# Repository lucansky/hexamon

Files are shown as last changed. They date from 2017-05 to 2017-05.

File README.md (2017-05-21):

# Hexamon.io - modular wireless beehive weighting system

Beehive monitoring - solves data acquisition from load cells placed under the beehives, data transport to server and data visualization for user.

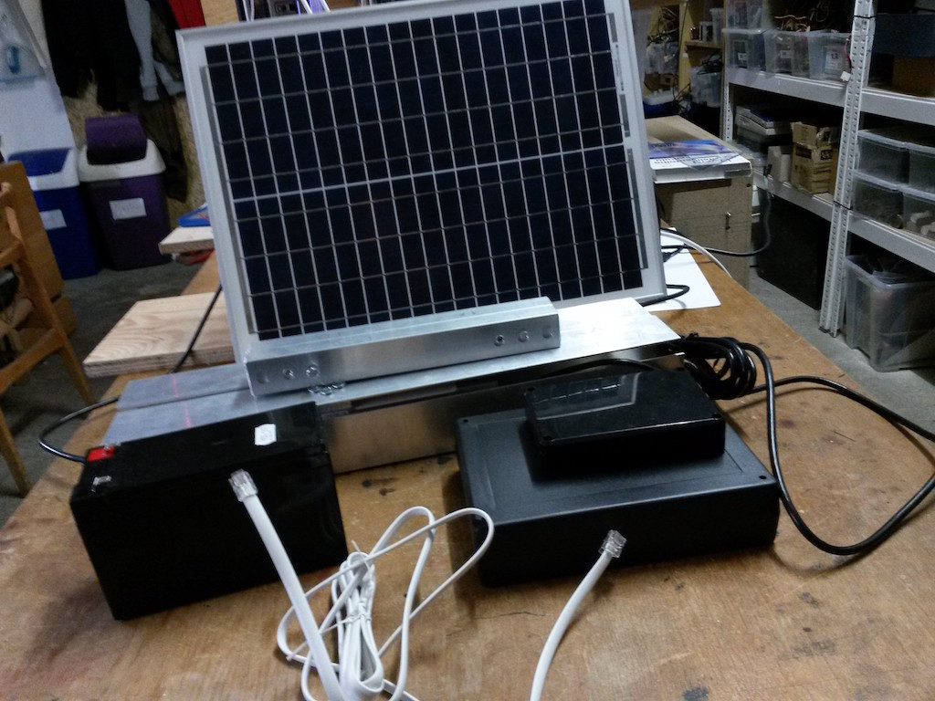
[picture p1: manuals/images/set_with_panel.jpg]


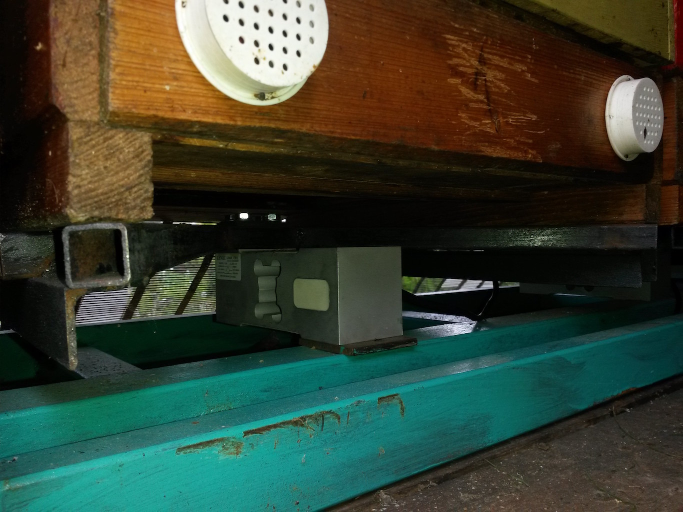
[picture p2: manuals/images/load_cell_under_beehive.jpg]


## Architecture overview
### Master
Master unit consist of a Raspberry Pi with a CAN shield with RJ12 connector.
CAN shield is a board with SPI [MCP2515 CAN controller](http://ww1.microchip.com/downloads/en/DeviceDoc/21801d.pdf) and [SN65HVD23x](http://www.ti.com/lit/ds/symlink/sn65hvd230.pdf) CAN transceiver.

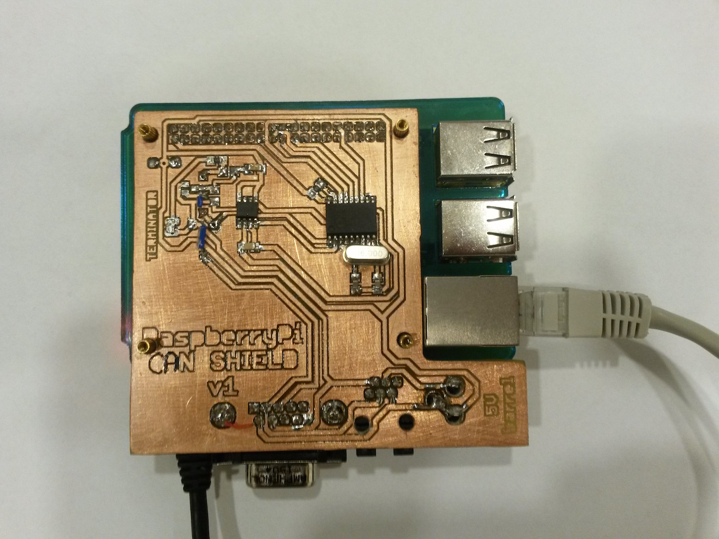
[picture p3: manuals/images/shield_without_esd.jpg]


### Power management
The system is powered through a [18V solar panel](https://www.i4wifi.cz/Solarni-panely-1/Solarni-panely/Solarni-panel-GWL-Sunny-Poly-20-Wp-36-cells-MPPT-18V.html), charging [12V battery](https://www.gme.cz/oloveny-akumulator-shimastu-npg7-2-12-12v-7-2ah).
Enclosure with master unit has power management board for charging circuit with under-voltage protection, as well as 5V USB ports for output.

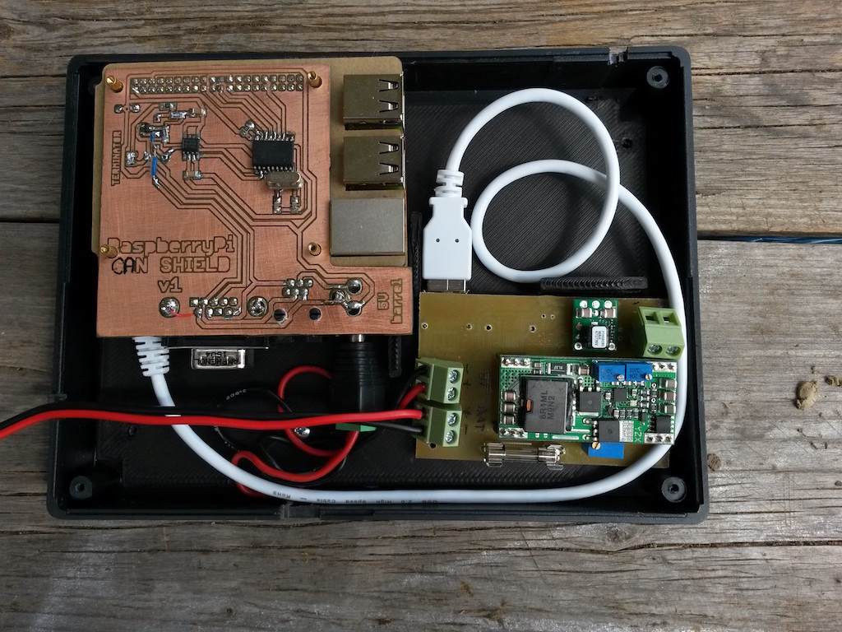
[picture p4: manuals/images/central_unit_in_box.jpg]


20W solar panel was selected for a prototype, due to it's ability to supply sufficient energy even during cloudy days for a Raspberry Pi.

### Bus unit
Under each beehive, assuming that whole chain of beehives is no longer than 100m, is placed platform with load cells for measuring the weight and bus unit in an enclosure. First beehive in chain contains Master and Bus unit at once.

Bus unit has STM32F042F6P6 in an TSSOP20 package with CAN transceiver and two RJ12 connectors for daisy-chaining to other bus units, as well as two holders for HX711 breakout boards. [Converters boards](https://www.aliexpress.com/item/10pcs-HX711-Weighing-Sensor-Dual-Channel-24-Bit-Precision-A-D-Module-Pressure-Sensor/32656264280.html) can be purchased through eBay or AliExpress.

Schematics & board design can be found in _boards_ directory.

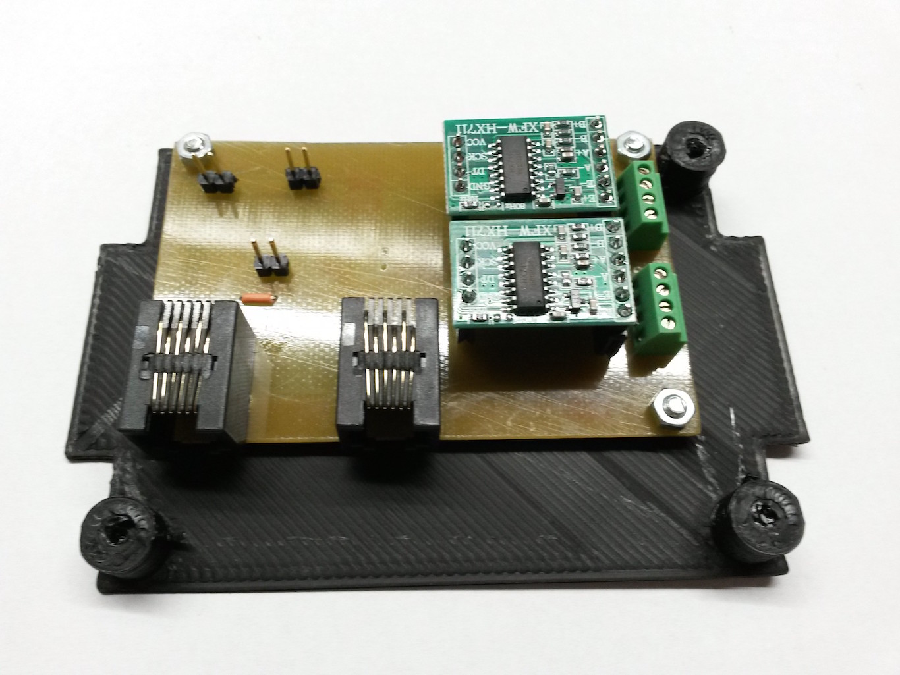
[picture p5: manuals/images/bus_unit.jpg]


### Weight acquisition
As an ADC with differential amplifier was selected chip HX711 integrated on a beakout board with all the necessary electronics around.

## Hardware
### Platform
Simple two-rail platform consists of three components:
* Load cell Zemic L6E or equivalent
* 2x Spacer
* 50x50mm 45cm L profile with drilled holes to match load-cell

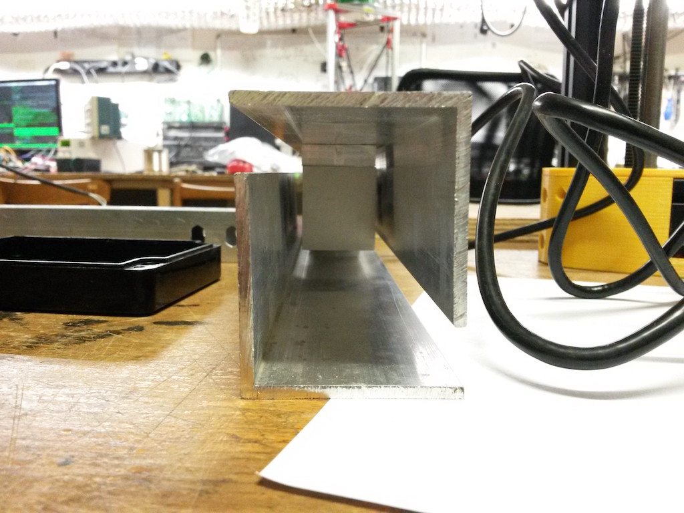
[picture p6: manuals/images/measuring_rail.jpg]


Middle bars may be optional, depending on the situation:
* 2x Rectangle aluminium profile 25x15x3mm 25cm
* 2x Rectangle aluminium profile 25x30x3mm 25cm
These fit perfectly together. By drilling holes, pitch can be adjusted.

As the platform was not part of the project assignment, [contact me](mailto:adamlucansky@gmail.com) in case of interest.

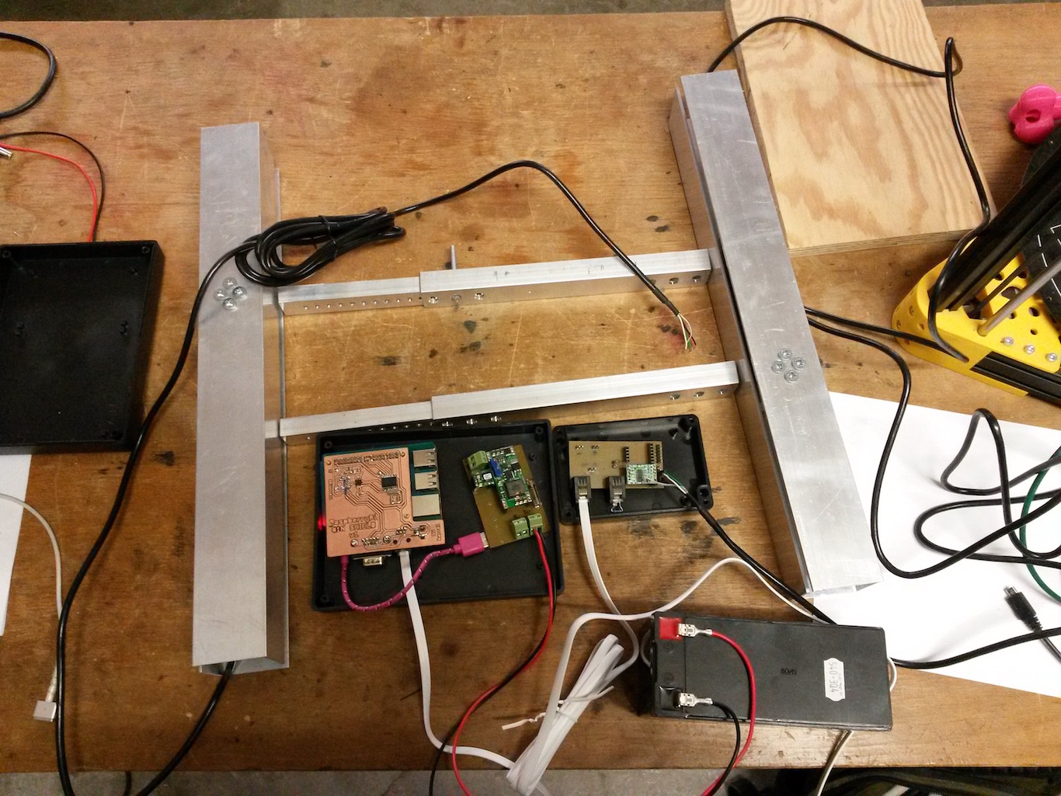
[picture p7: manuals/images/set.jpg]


### Load cells
During development, [Zemic L6E](https://www.zemiceurope.com/media/Documentation/L6E_Datasheet.pdf) were selected. For deployment, [L6G](https://www.zemiceurope.com/media/Documentation/L6G_Datasheet.pdf) are used. 

## Modularity
Several beehives can be chained together with a telephone cable with RJ12 jack through Bus unit under beehive, while master unit is sending captured data wirelessly to server through WiFi (3G/GSM modem option was tested and implemented, but is not further described, wvdial utility & whole ecosystem of linux drivers for modems make it diffucult for set-up).

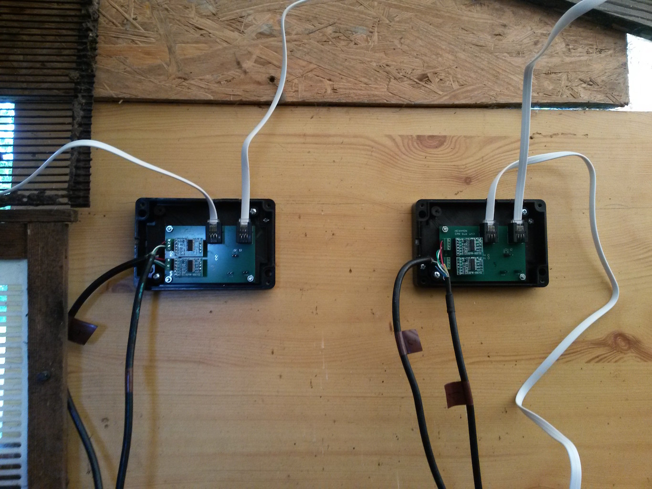
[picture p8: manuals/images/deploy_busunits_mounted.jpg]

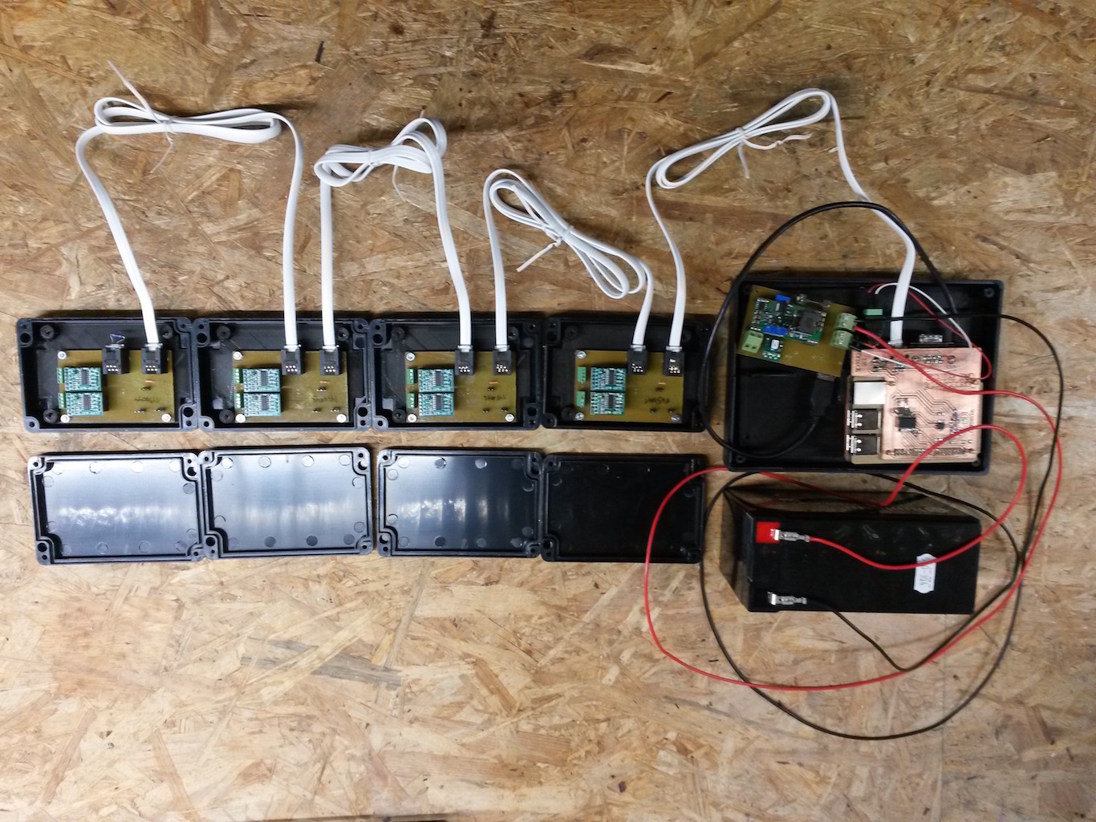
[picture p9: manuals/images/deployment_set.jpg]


## Software
### Master unit
Raspberry Pi 3 running Raspbian system, with an SPI overlay, provides can0 network interface which can be easily interfaced through linux socket. [Main program](https://github.com/lucansky/hexamond) is written in Haskell and is basically flipping frames received on CAN bus to HTTP requests to webservers where the data are further processed.

### Bus unit
[STM32F042](http://www.st.com/en/microcontrollers/stm32f0x2.html) MCU on board has 32kB of Flash memory and 6kB SRAM. Ivory language has been selected for generation of the C code, and Ivory framework as a hardware abstraction layer, message passing and RTOS interaction. Therefore whole project is 100% Haskell except the web. Firmware can be found [HERE](https://github.com/lucansky/hexamon-firmware).

### Web
Web interface provides charts for all sensors connected to the network as well as dashboard defined by user for aggregated statistics. Each setup requires separate instance of the web with database. Source code can be found [HERE](https://github.com/lucansky/hexamon-web)

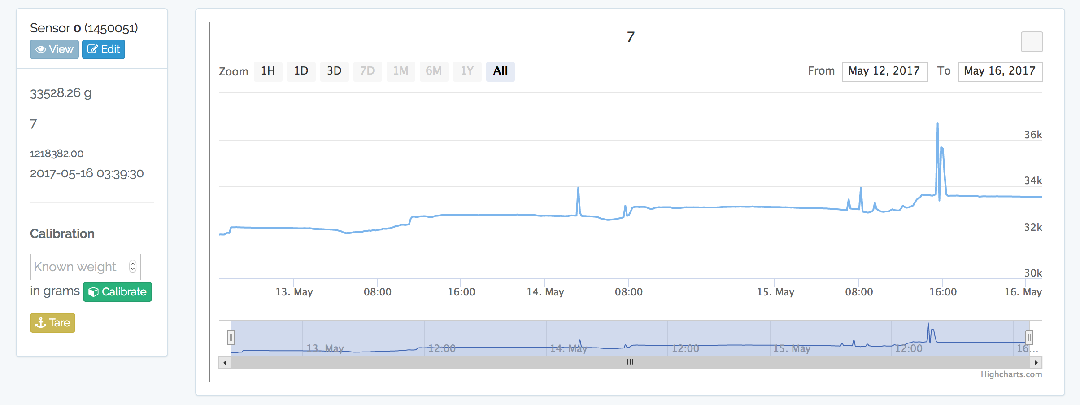
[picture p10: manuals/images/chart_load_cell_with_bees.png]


# Results
System is deployed on a few beehives, needs a bit more tweaking (grounding of the metal platform with beehives, as interference is generated during thunderstorm) and better cable management.

__candump__ can be seed on monitor of the laptop of the deployment set. Battery is already charging from solar panel.
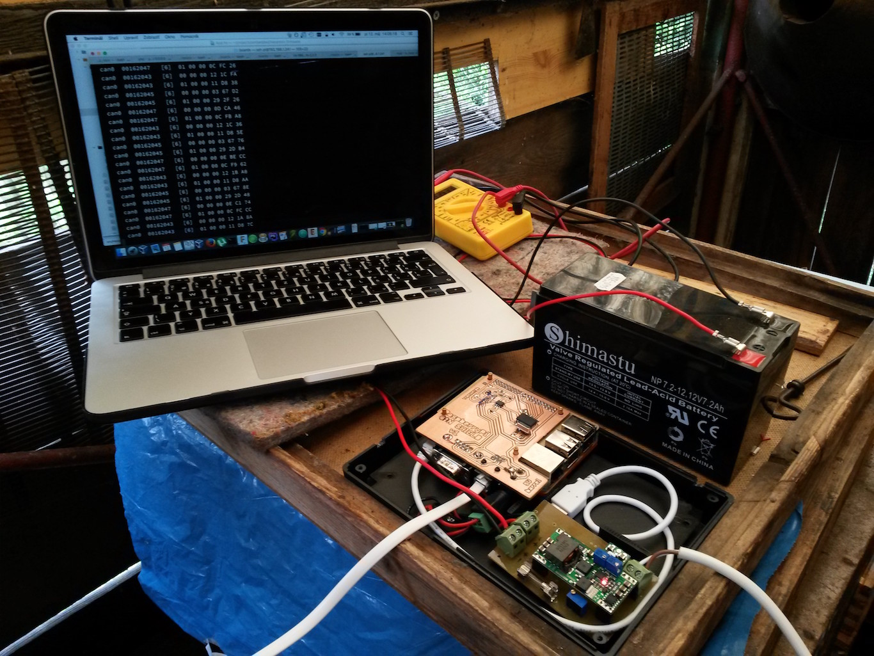
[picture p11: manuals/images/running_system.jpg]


# Future work
Due to over-engineered solution, next iteration will be with [SIGFOX](https://en.wikipedia.org/wiki/Sigfox) - one module per beehive (just load cell cable connected to small box, 2xAA battery, optionally DS18B20 temperature sensor). Currently waiting for a [better signal coverage in Slovakia](http://www.simplecell.sk/pages/technologia_sigfox/), which is the reason SIGFOX was not considered from the beginning.

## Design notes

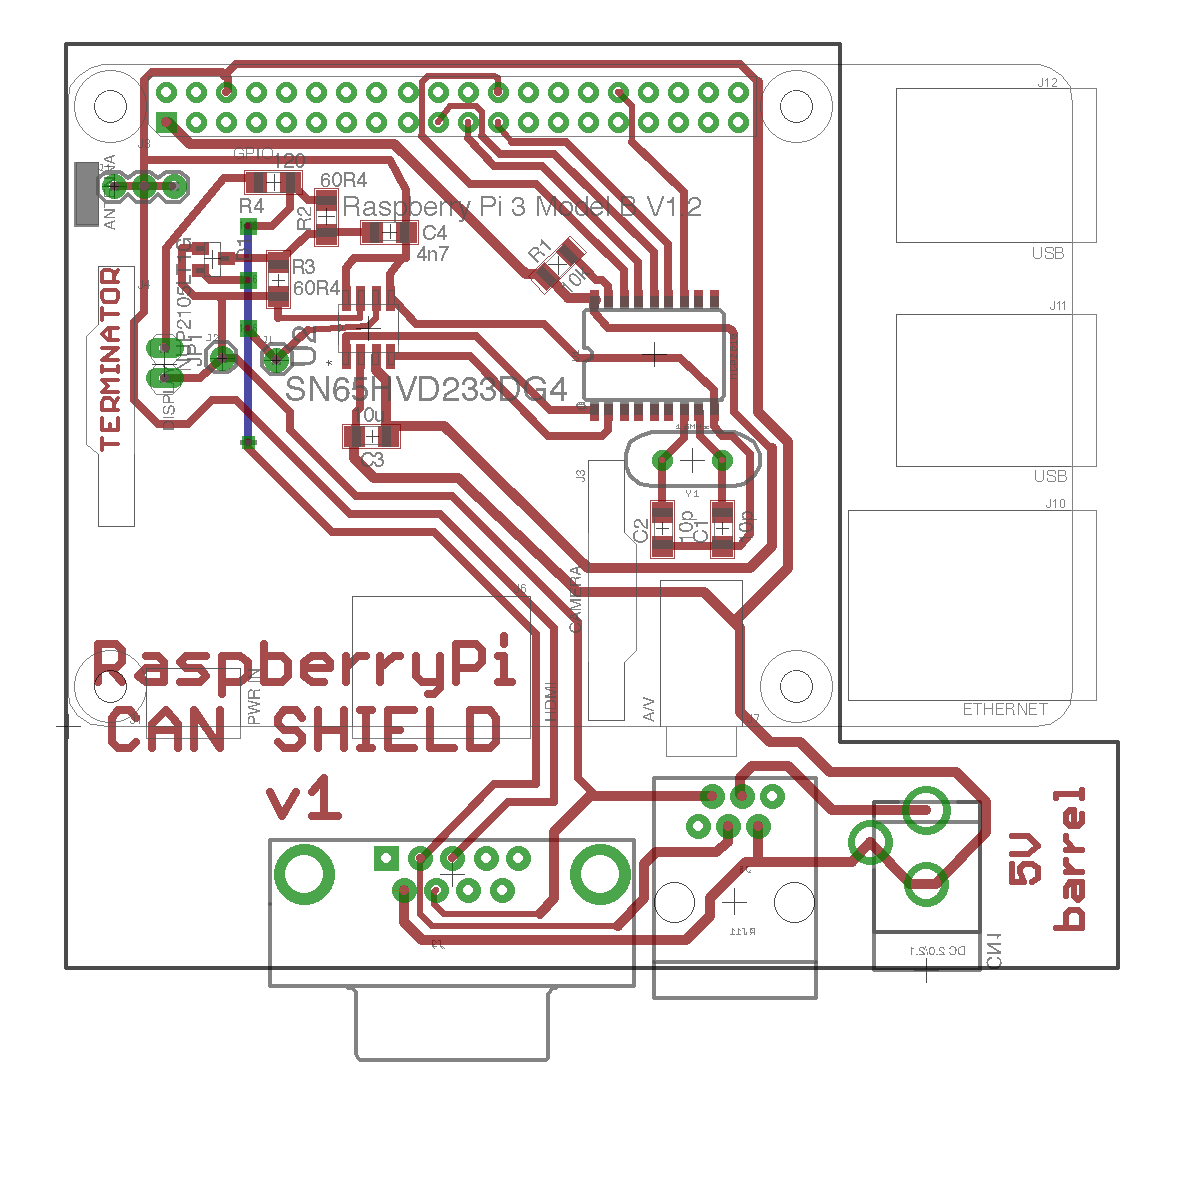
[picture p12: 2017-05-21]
boards/master_can_shield/board_image.png

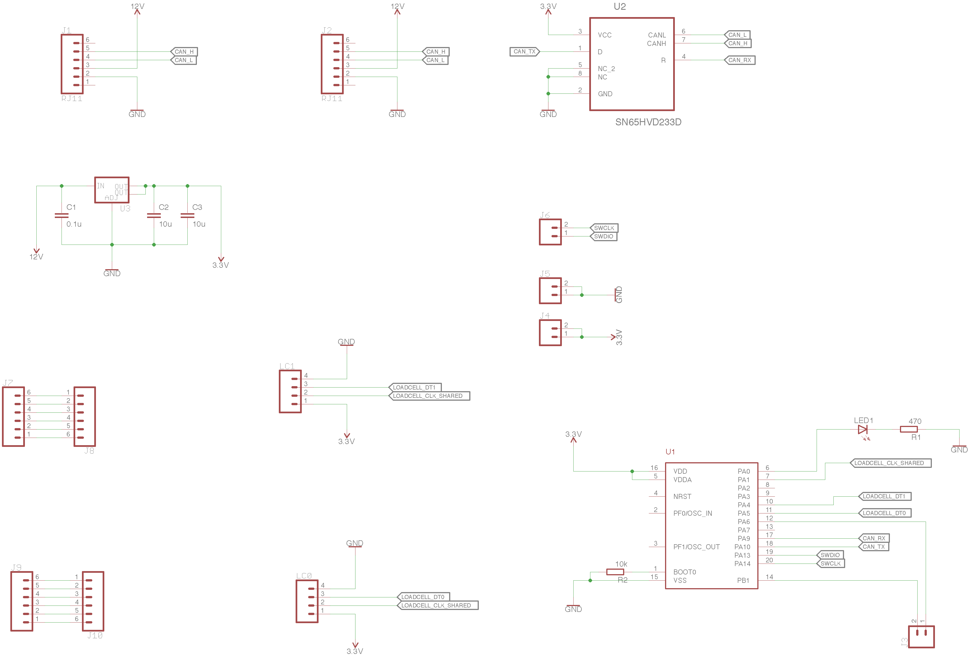
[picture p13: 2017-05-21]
boards/busunit/schema_image.png

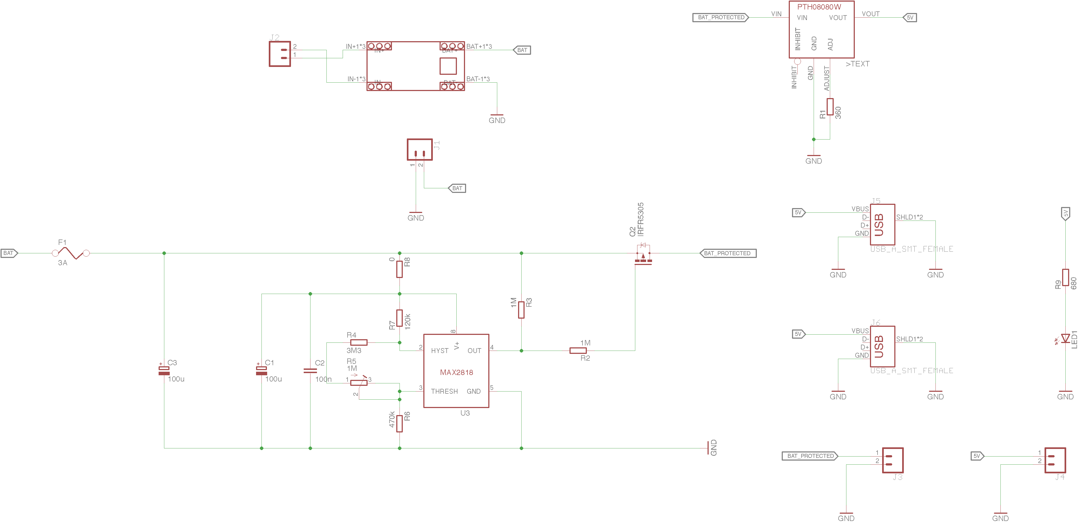
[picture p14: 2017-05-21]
boards/power_board/schema_image.png

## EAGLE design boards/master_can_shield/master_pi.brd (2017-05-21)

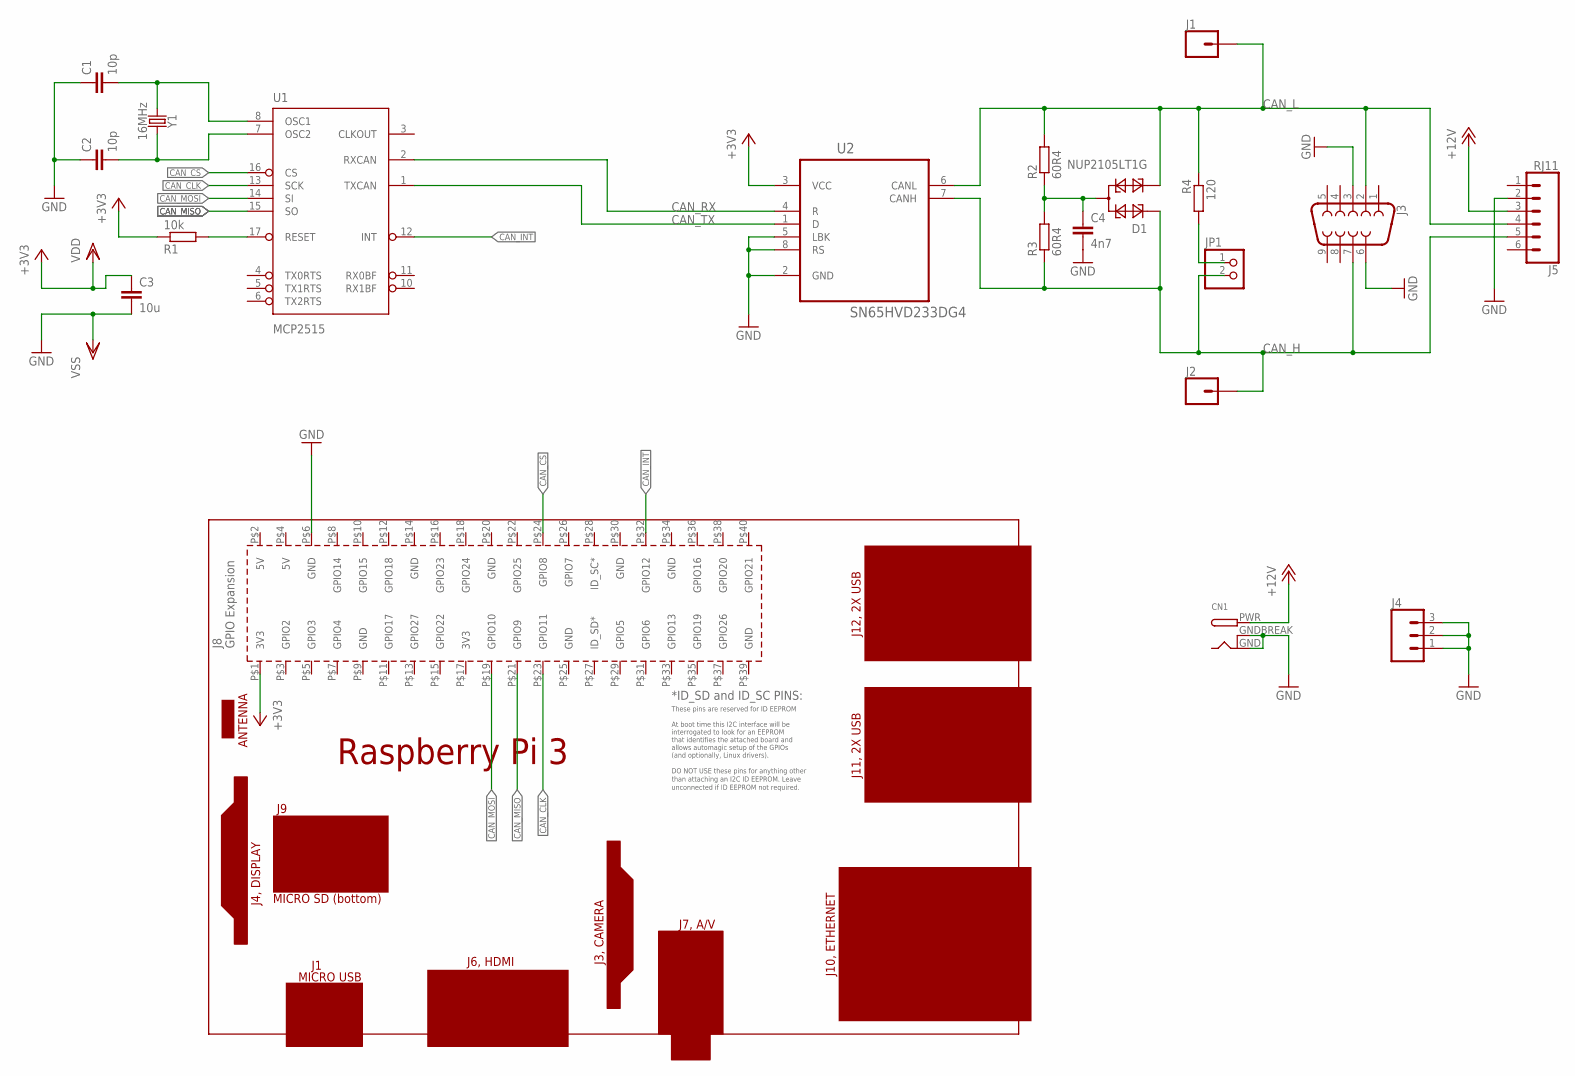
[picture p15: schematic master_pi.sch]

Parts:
C1, C2: 10p; C1206
C3: 10u; C1206
C4: 4n7; C1206
CN1: DCBARRELPTH; DCJACK_2MM_PTH
D1: NUP2105LT1G; SOT23
J1, J2: CONN_01; 1X01
J3: DB9FEMALE; DB9
J4: CONN_03; 1X03
J5: RJ11; RJ11-6
JP1: PINHD-1X2; 1X02
PCB1: RPI3
R1: 10k; R1206
R2, R3: 60R4; R1206
R4: 120; R1206
U1: MCP2515; SO18W
U2: SN65HVD233DG4; SOIC127P600X175-8N
Y1: 16MHz; HC49US

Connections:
+3V3: C3.1, PCB1.P$1 (3V3), R1.1, U1.18 (VDD), U2.3 (VCC)
+12V: CN1.PWR, J5.3
CAN_CLK: PCB1.P$23 (GPIO11), U1.13 (SCK)
CAN_CS: PCB1.P$24 (GPIO8), U1.16 (CS)
CAN_H: D1.1, J2.1, J3.7, J5.5, JP1.2, R3.1, U2.7 (CANH)
CAN_INT: PCB1.P$32 (GPIO12), U1.12 (INT)
CAN_L: D1.2, J1.1, J3.2, J5.4, R2.2, R4.1, U2.6 (CANL)
CAN_MISO: PCB1.P$21 (GPIO9), U1.15 (SO)
CAN_MOSI: PCB1.P$19 (GPIO10), U1.14 (SI)
CAN_RX: U1.2 (RXCAN), U2.4 (R)
CAN_TX: U1.1 (TXCAN), U2.1 (D)
GND: C1.1, C2.1, C3.2, C4.2, CN1.GND, CN1.GNDBREAK, J3.3, J3.6, J4.1, J4.2, J4.3, J5.2, PCB1.P$6 (GND), U1.9 (VSS), U2.2 (GND), U2.5 (LBK), U2.8 (RS)
unnamed: R1.2, U1.17 (RESET)
unnamed: C4.1, D1.3, R2.1, R3.2
unnamed: C1.2, U1.8 (OSC1), Y1.1
unnamed: C2.2, U1.7 (OSC2), Y1.2
unnamed: JP1.1, R4.2

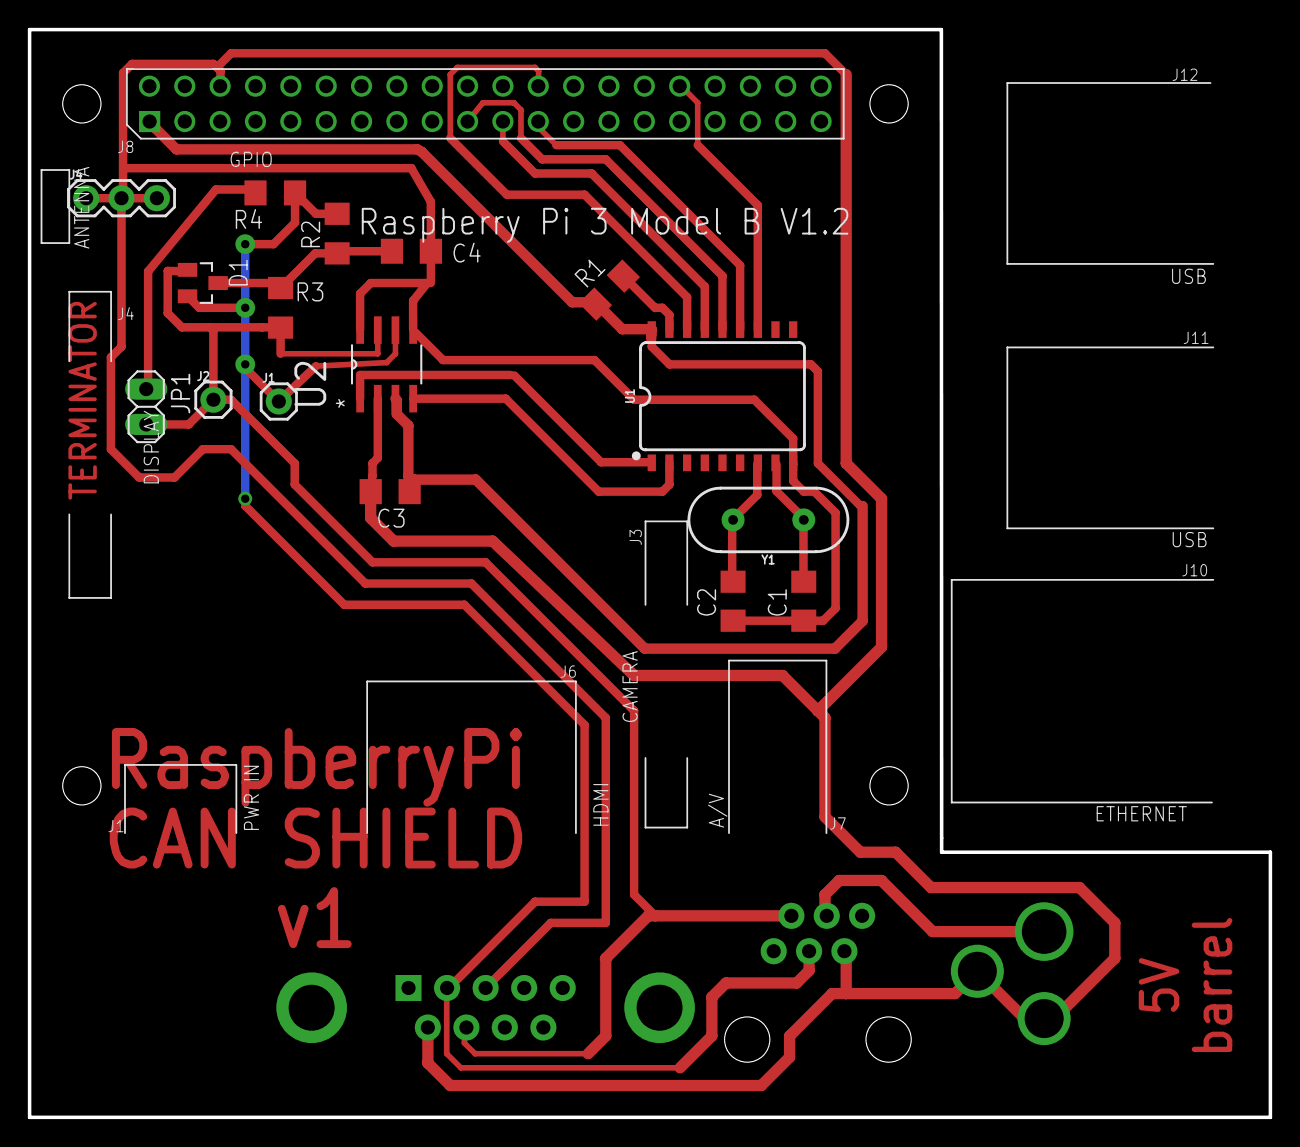
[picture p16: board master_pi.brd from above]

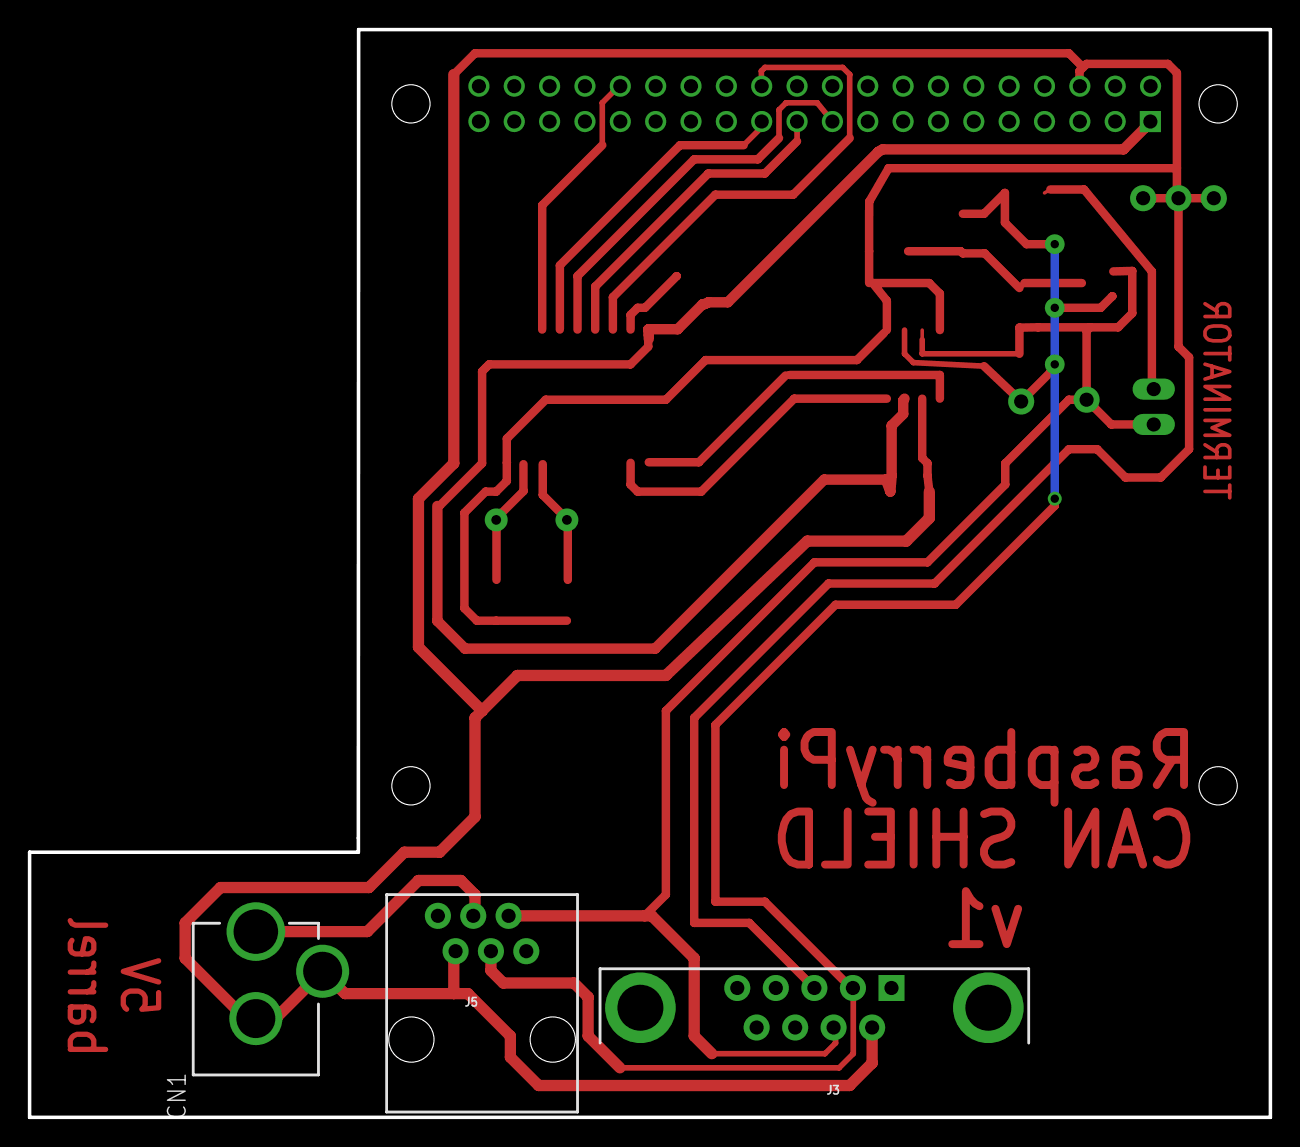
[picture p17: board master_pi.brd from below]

Board: 2 copper layers, 89.2 x 78.2 mm, 20 parts (3 on the bottom side), 17 nets.

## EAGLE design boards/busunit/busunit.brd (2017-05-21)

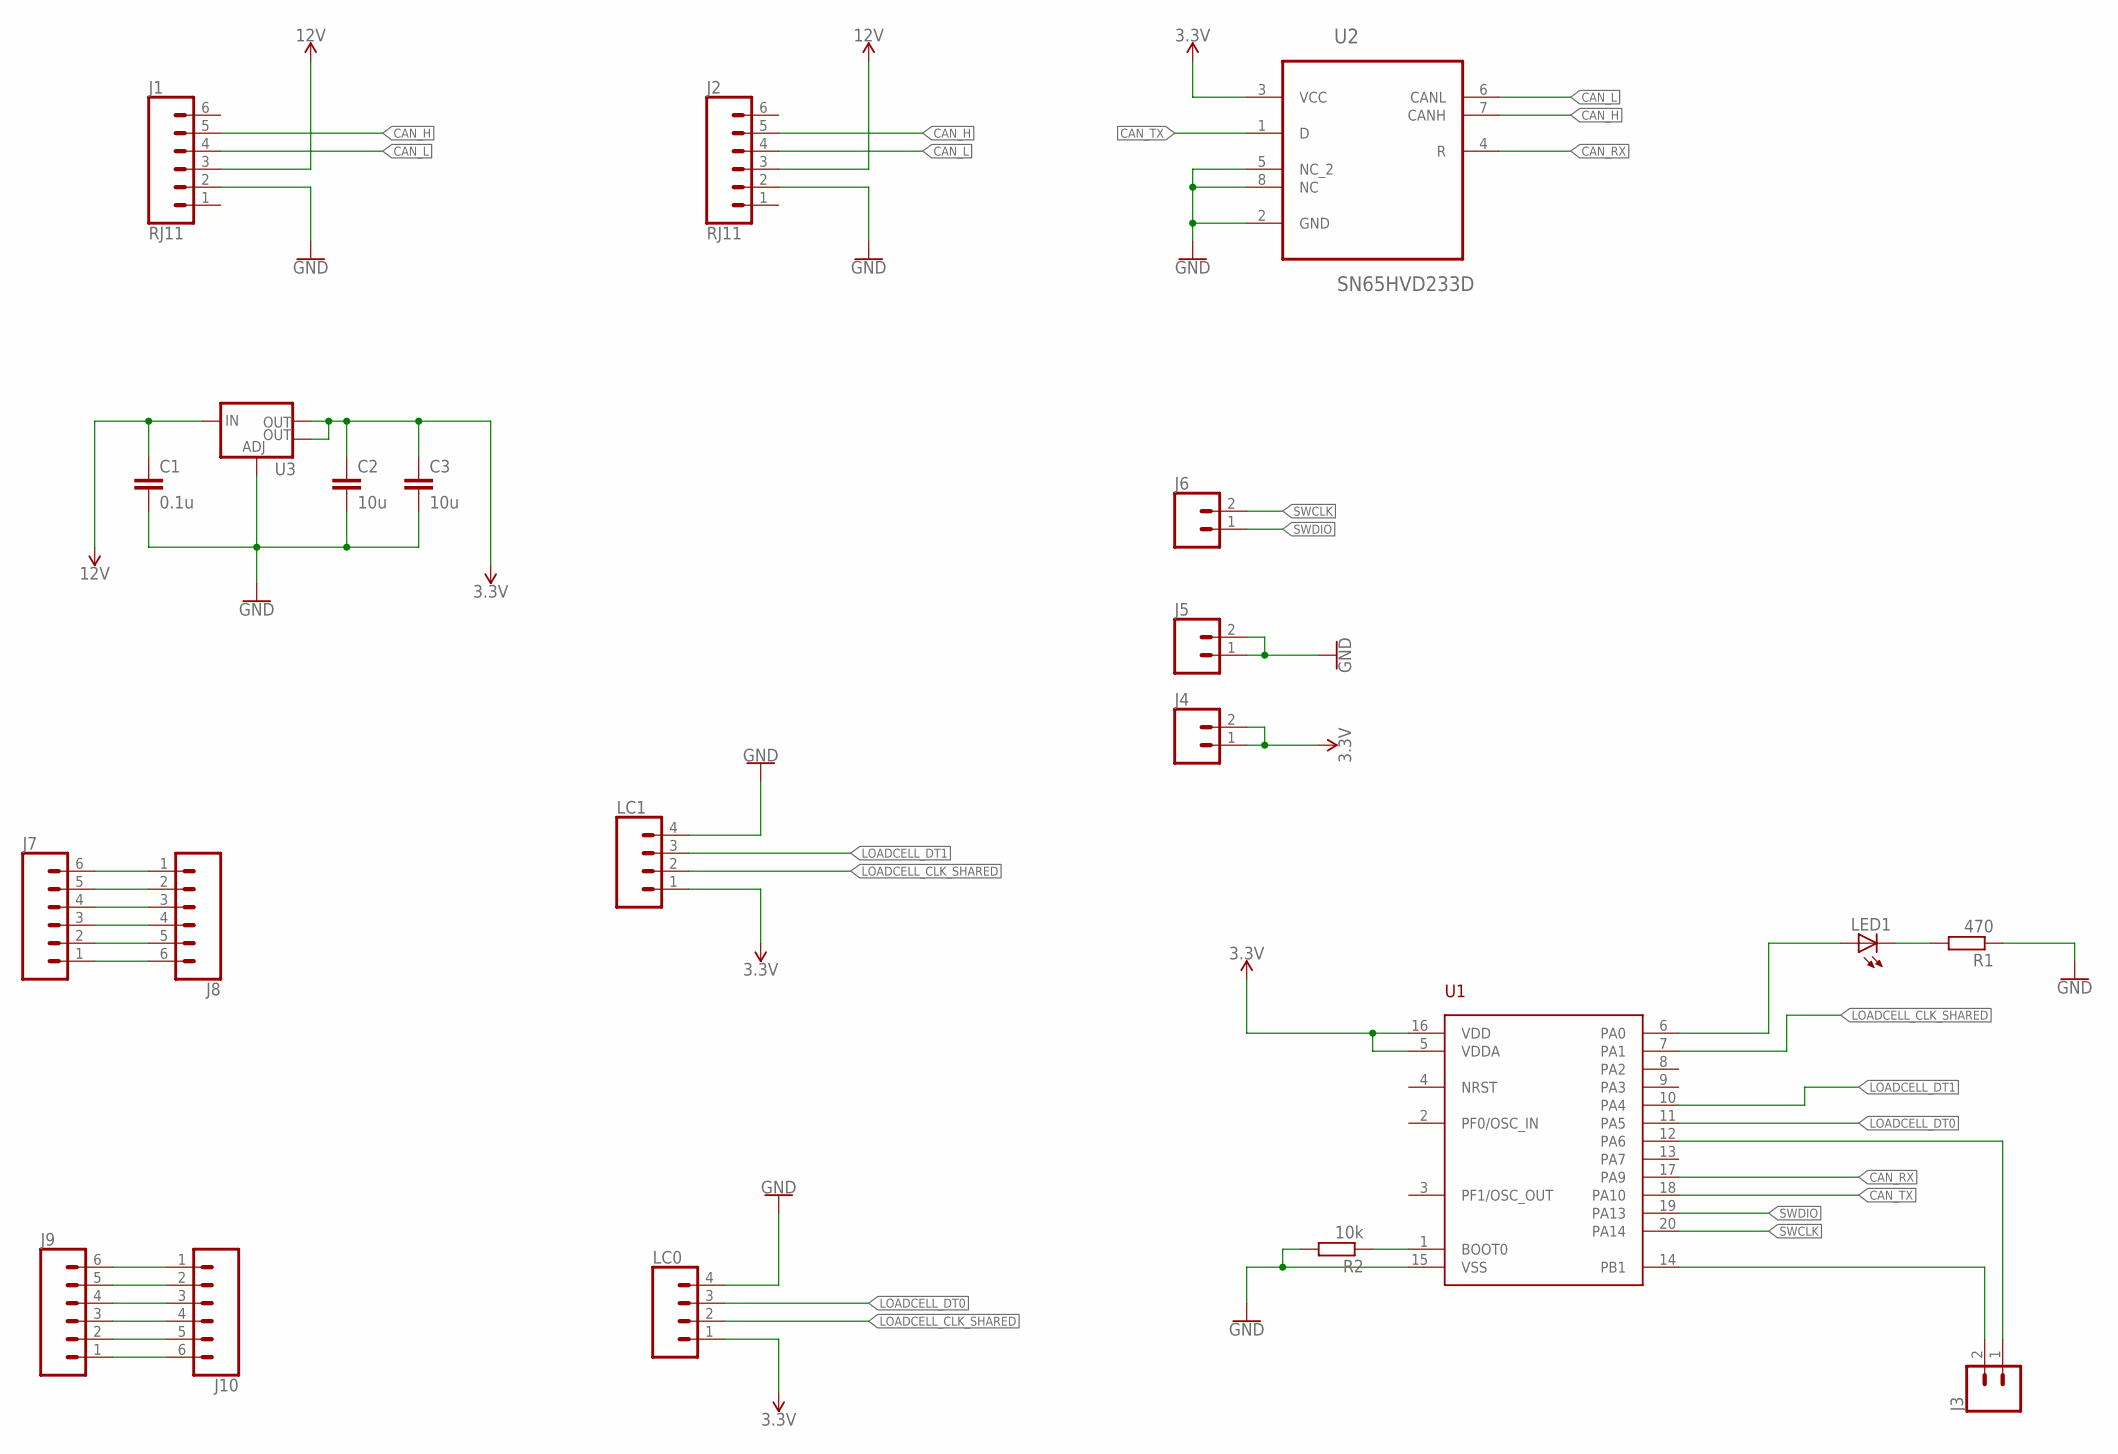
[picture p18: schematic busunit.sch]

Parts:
C1: 0.1u; C1206K
C2, C3: 10u; C1206K
J1, J2: RJ11; RJ11-6
J3, J4, J5, J6: CONN_02; 1X02
J7, J8, J9, J10: CONN_06SILK_FEMALE_PTH; 1X06
LC0, LC1: CONN_04; 1X04
LED1: LEDCHIPLED_1206; CHIPLED_1206
R1: 470; R1206
R2: 10k; R1206
U1: STM32F030F4; TSSOP20
U2: SN65HVD233D; SOIC127P600X175-8N
U3: V_REG_LM1117SOT223; SOT223

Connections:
3.3V: C2.1, C3.1, J4.1, J4.2, LC0.1, LC1.1, U1.5 (VDDA), U1.16 (VDD), U2.3 (VCC), U3.2 (OUT), U3.4 (OUT)
12V: C1.1, J1.3, J2.3, U3.3 (IN)
CAN_H: J1.5, J2.5, U2.7 (CANH)
CAN_L: J1.4, J2.4, U2.6 (CANL)
CAN_RX: U1.17 (PA9), U2.4 (R)
CAN_TX: U1.18 (PA10), U2.1 (D)
GND: C1.2, C2.2, C3.2, J1.2, J2.2, J5.1, J5.2, LC0.4, LC1.4, R1.1, R2.2, U1.15 (VSS), U2.2 (GND), U2.5 (NC_2), U2.8 (NC), U3.1 (ADJ)
LED: LED1.A, U1.6 (PA0)
LOADCELL_CLK_SHARED: LC0.2, LC1.2, U1.7 (PA1)
LOADCELL_DT0: LC0.3, U1.11 (PA5)
LOADCELL_DT1: LC1.3, U1.10 (PA4)
unnamed: R2.1, U1.1 (BOOT0)
unnamed: LED1.C, R1.2
unnamed: J9.6, J10.1
unnamed: J9.5, J10.2
unnamed: J9.4, J10.3
unnamed: J9.3, J10.4
unnamed: J9.2, J10.5
unnamed: J9.1, J10.6
unnamed: J7.1, J8.6
unnamed: J7.2, J8.5
unnamed: J7.3, J8.4
unnamed: J7.4, J8.3
unnamed: J7.5, J8.2
unnamed: J7.6, J8.1
PA6: J3.1, U1.12 (PA6)
PB1: J3.2, U1.14 (PB1)
SWCLK: J6.2, U1.20 (PA14)
SWDIO: J6.1, U1.19 (PA13)

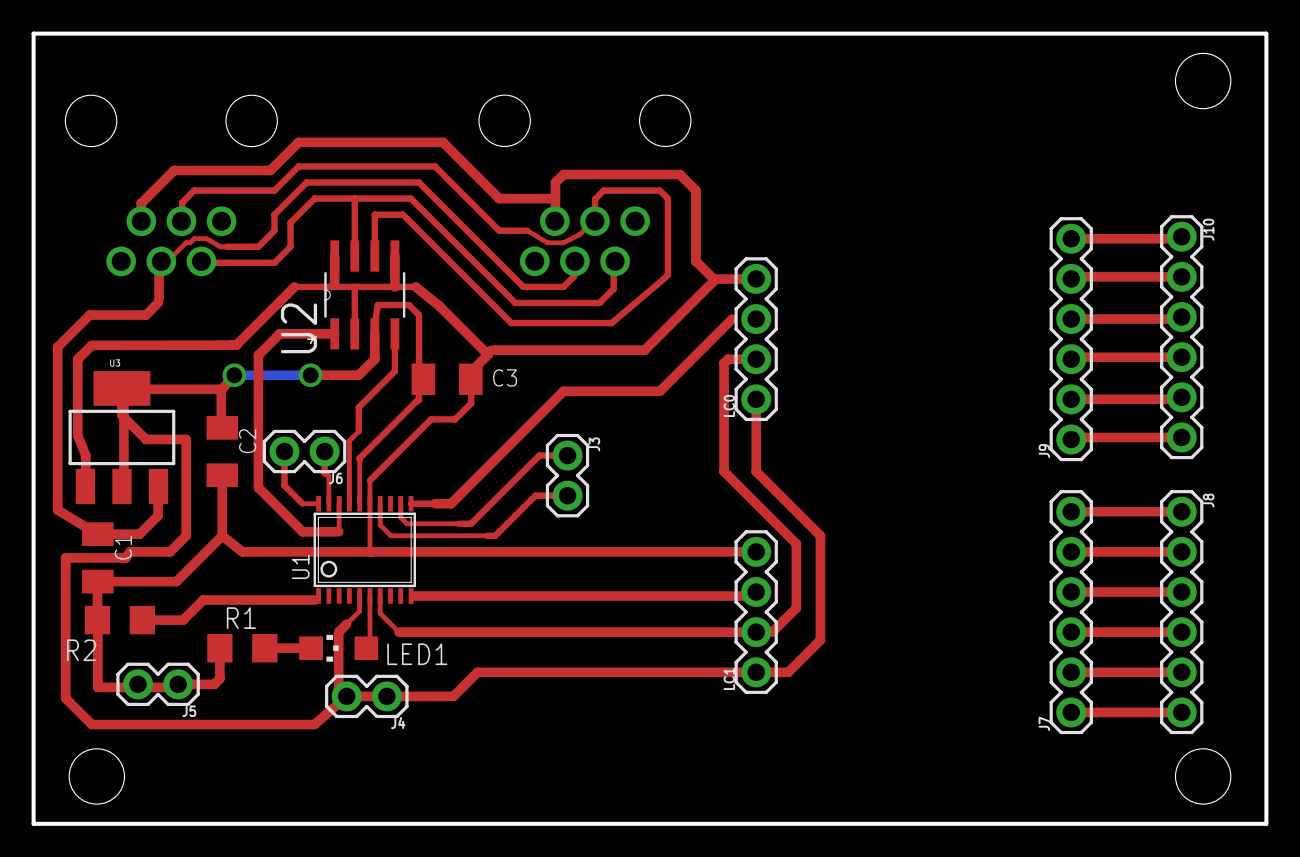
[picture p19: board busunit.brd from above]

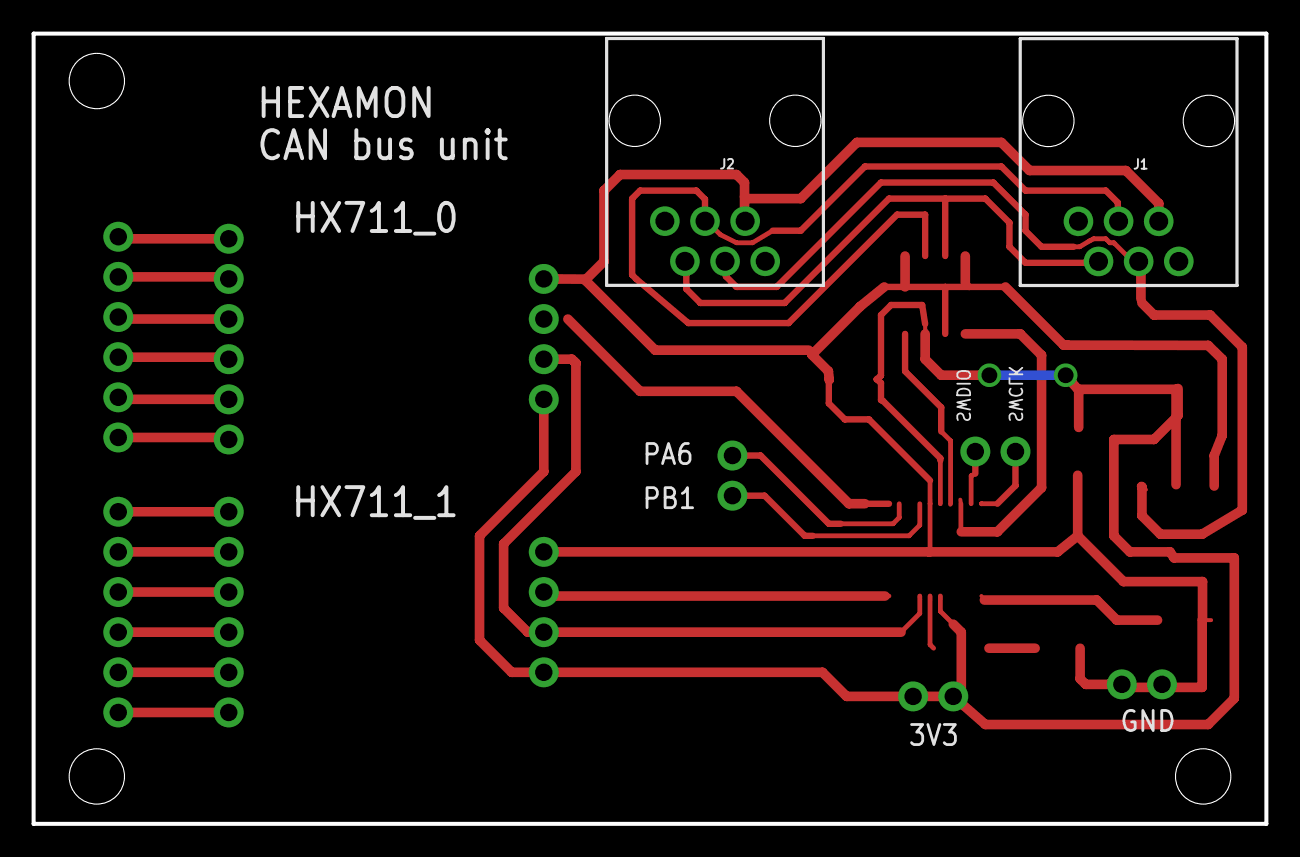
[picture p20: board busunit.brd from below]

Board: 2 copper layers, 78.0 x 50.0 mm, 21 parts (2 on the bottom side), 29 nets.

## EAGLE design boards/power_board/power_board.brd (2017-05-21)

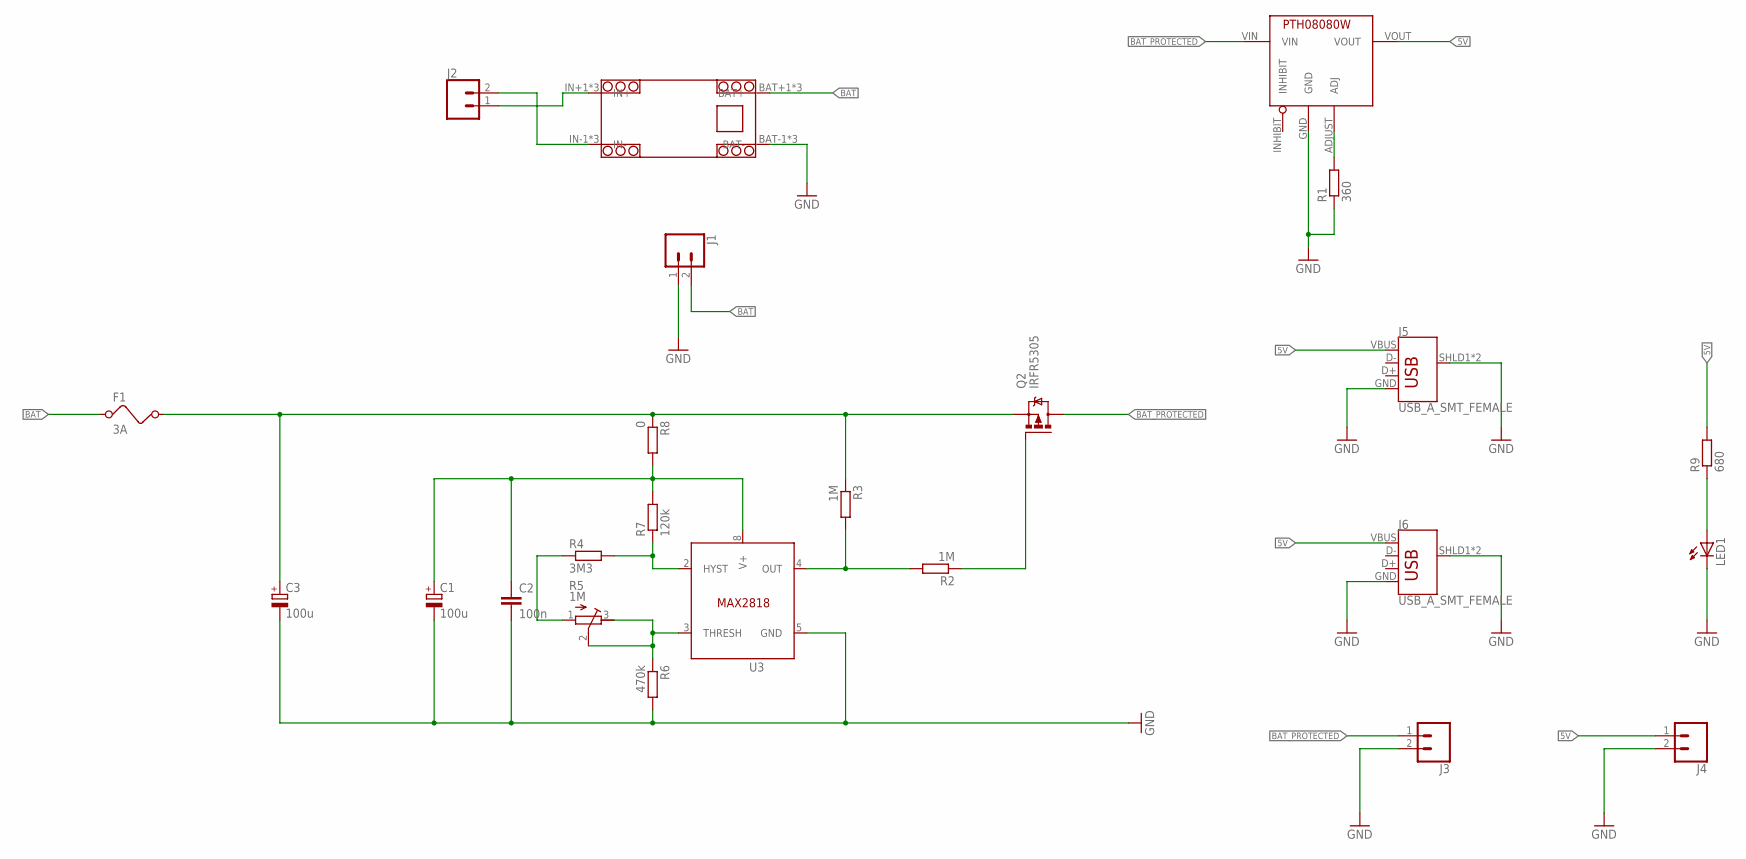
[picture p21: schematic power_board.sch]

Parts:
C1, C3: 100u; E3,5-8
C2: 100n; C1206
F1: 3A; FUSE
J1, J2, J4: CONN_025MM; SCREWTERMINAL-5MM-2
J3: CONN_02; 1X02
J5, J6: USB_A_SMT_FEMALE; USB-A-S-SILK-FEMALE
LED1: LED3MM
Q2: IRFR5305; D-PAK_TO252AA
R1: 360; R1206
R2, R3: 1M; R1206
R4: 3M3; R1206
R5: 1M; RTRIM64Y
R6: 470k; R1206
R7: 120k; R1206
R8: 0; R1206
R9: 680; R1206
U1: YZXSTUDIO_SOLARCHARGERDEFAULT; YZXSTUDIO_SOLARCHARGER
U2: PTH08080WPTH08080W; PTH08080W
U3: MAX2812MAX2812_SOIC8; SOIC127P600X175-8N

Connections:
5V: J4.1, J5.VBUS, J6.VBUS, R9.2, U2.VOUT
BAT: F1.1, J1.2, U1.BAT+1 (BAT+), U1.BAT+2 (BAT+), U1.BAT+3 (BAT+)
BAT_FUSED: C3.+, F1.2, Q2.3 (S), R3.1, R8.1
BAT_PROTECTED: J3.1, Q2.4 (D), U2.VIN
GND: C1.-, C2.2, C3.-, J1.1, J3.2, J4.2, J5.GND, J5.SHLD1 (SHIELD), J5.SHLD2 (SHIELD), J6.GND, J6.SHLD1 (SHIELD), J6.SHLD2 (SHIELD), LED1.K (C), R1.1, R6.2, U1.BAT-1 (BAT-), U1.BAT-2 (BAT-), U1.BAT-3 (BAT-), U2.GND, U3.5 (GND)
unnamed: J2.2, U1.IN-1 (IN-), U1.IN-2 (IN-), U1.IN-3 (IN-)
unnamed: J2.1, U1.IN+1 (IN+), U1.IN+2 (IN+), U1.IN+3 (IN+)
unnamed: R1.2, U2.ADJUST (ADJ)
unnamed: R5.2 (S), R5.3 (E), R6.1, U3.3 (THRESH)
unnamed: R2.2, R3.2, U3.4 (OUT)
unnamed: Q2.1 (G), R2.1
unnamed: C1.+, C2.1, R7.2, R8.2, U3.8 (V+)
unnamed: R4.2, R7.1, U3.2 (HYST)
unnamed: R4.1, R5.1 (A)
unnamed: LED1.A, R9.1

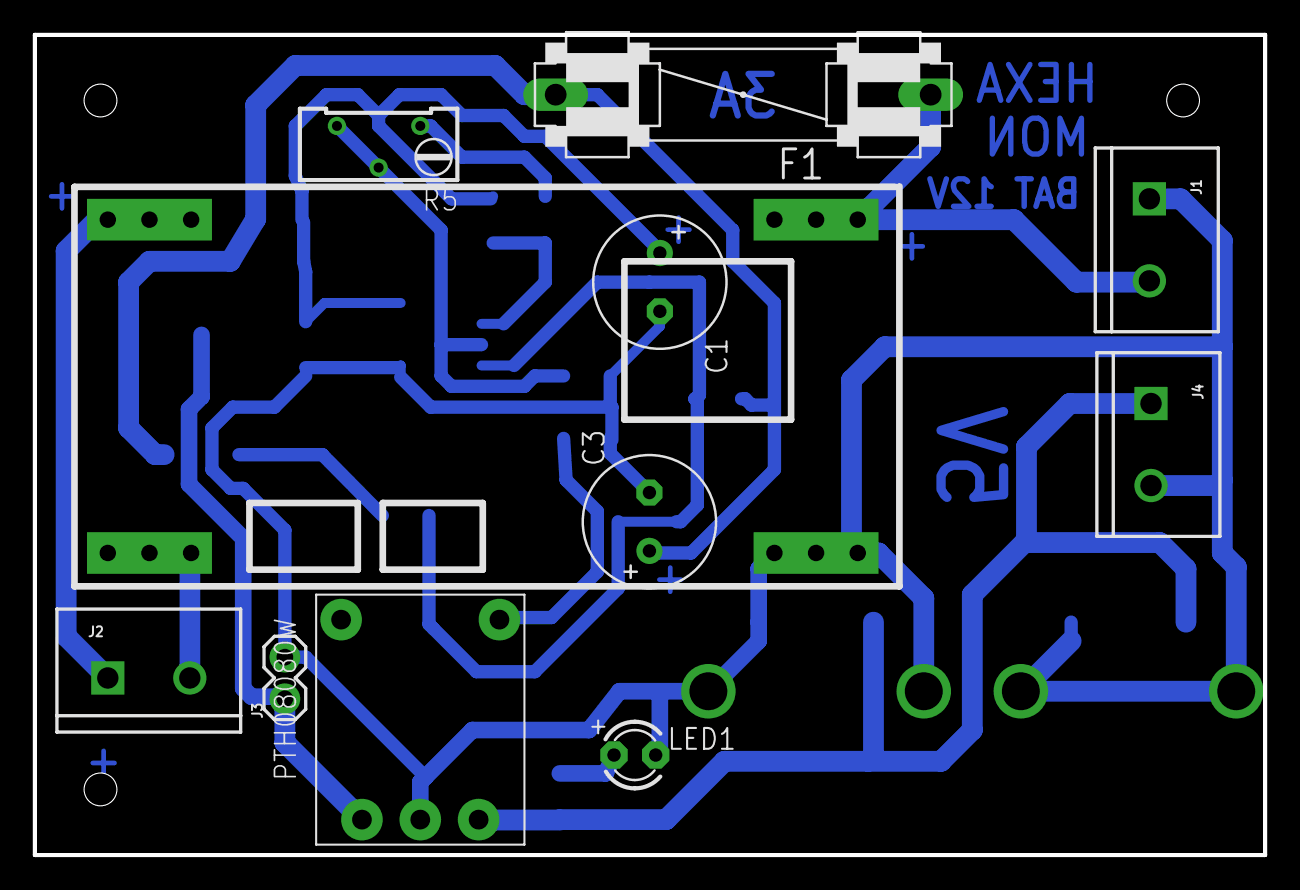
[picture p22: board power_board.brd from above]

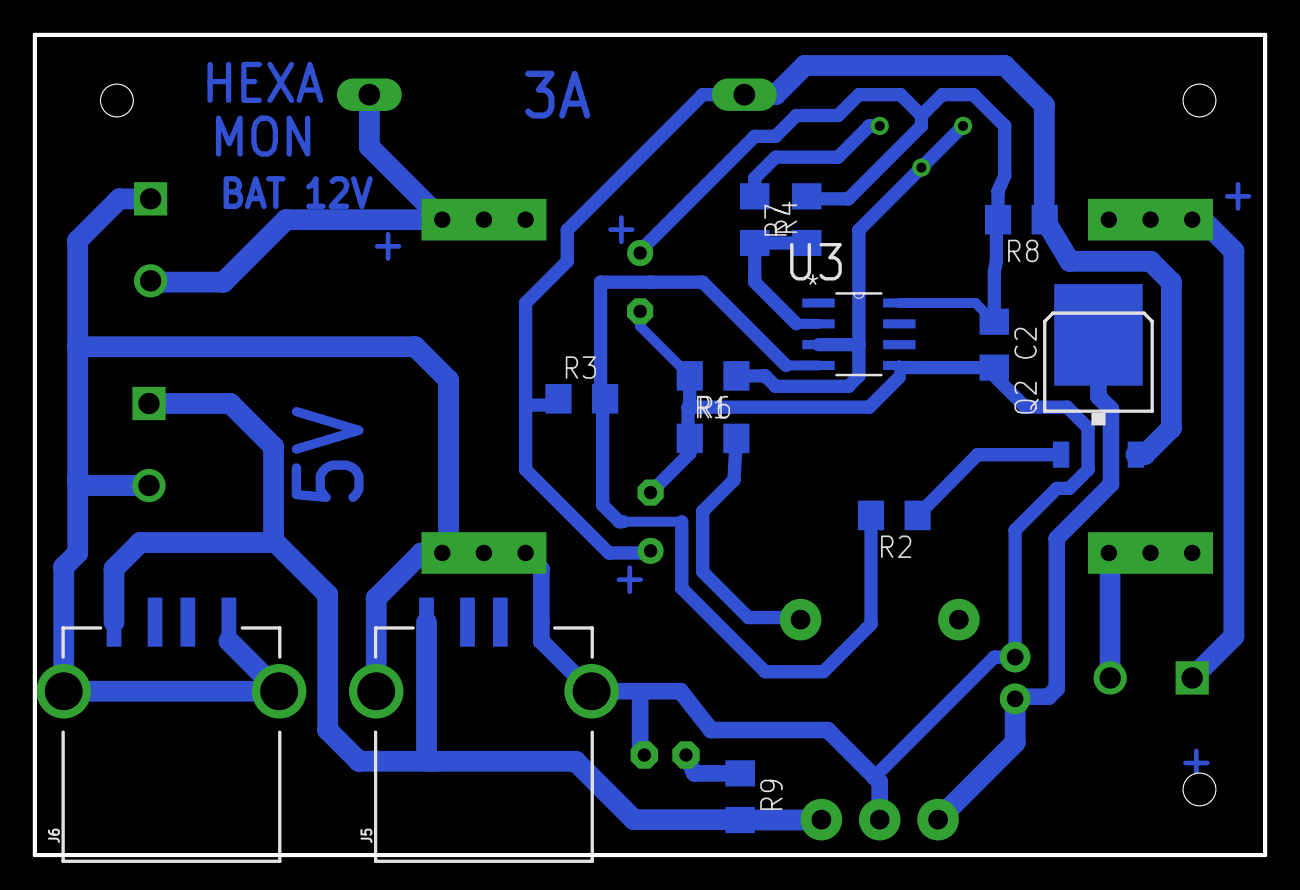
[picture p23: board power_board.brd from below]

Board: 2 copper layers, 75.0 x 50.0 mm, 24 parts (13 on the bottom side), 15 nets.

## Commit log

2017-04-30 Going public with boards
    [busunit.brd, busunit.sch, master_pi.brd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]
2017-05-01 Moved some labels to bottom layer in busunit, exported libraries.
    [busunit.brd]
2017-05-16 Minor modifications, images of board & schema included
    [busunit.brd, busunit.sch, power_board.brd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]

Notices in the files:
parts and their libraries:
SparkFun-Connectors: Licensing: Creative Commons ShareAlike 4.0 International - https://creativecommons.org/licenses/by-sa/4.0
